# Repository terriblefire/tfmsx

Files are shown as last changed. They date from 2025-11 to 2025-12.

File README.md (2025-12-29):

# TFMSX







A homebrew MSX2 machine using as many of the original chips as possible, with custom CPLD logic to implement the MSX slot system, memory mapper, and bus interface.

## Discord

Join the TF discord for help 

https://discord.gg/Q5zfusgnmH 

## Overview

TFMSX is an open-source hardware implementation of the MSX2 standard that combines authentic MSX chips (VDP, PSG, CPU) with modern programmable logic. The design uses a Xilinx XC95288XL CPLD to handle:

- MSX slot system (4 primary slots + secondary slot expansion)
- Memory mapper (512KB SRAM organized as 32 pages of 16KB)
- I/O address decoding and bus arbitration
- Clock generation and distribution
- Real-time clock (RP5C01A) interface

## Features

- **MSX2 Compatible**: Full MSX2 slot architecture with expansion capability
- **Original Components**: Uses genuine Yamaha V9958 VDP, YM2149 PSG, Z80 CPU
- **512KB RAM**: Memory mapper providing 32 banks of 16KB
- **Real-time Clock**: RP5C01A battery-backed RTC
- **Expansion Slots**: Support for cartridges and expansion boards
- **Multiple Revisions**: Hardware evolved through rev0 → rev1 → rev2 with improvements
- **Comprehensive Testing**: Automated test suite with CI/CD integration

## Hardware Revisions

The current repository contains the **Rev 2** design (see `boards/tfmsxr2/`), which includes:

- Improved audio output and PSG interface
- VDP reset control
- SRAM write enable (SWR pin)
- Fixed WAIT signal generation for proper Z80 timing
- Corrected slot select logic

Previous hardware revisions (Rev 0, Rev 1) are documented in the Eagle design files under `eagle/tfmsx_rev*.brd/sch`.

## Repository Structure

```
tfmsx/
├── rtl/                    # Verilog RTL source code
│   ├── tfmsx_top.v        # Top-level CPLD module
│   ├── clocks.v           # Clock generation (CPU, PSG, slot clocks)
│   └── rp5c01a.v          # Real-time clock module
├── boards/                 # Board-specific build configurations
│   ├── tfmsxr2/           # Revision 2 board (current)
│   ├── Makefile.cpld      # Common CPLD build rules
│   ├── Makefile.inc       # Docker/Xilinx environment setup
│   └── boards.txt         # List of board configurations
├── testsuite/             # Verification test benches
│   ├── bus/               # Bus interface tests (SRAM, ROM, VDP, PSG, slots)
│   │   ├── test_sram_access.v    # SRAM read/write tests
│   │   ├── test_rom_access.v     # ROM access tests
│   │   ├── test_vdp_io.v         # VDP I/O tests
│   │   ├── test_psg_io.v         # PSG I/O tests
│   │   ├── test_slot_access.v    # Slot system tests
│   │   ├── bus_fixture.vinc      # Common test fixture
│   │   ├── bus_tasks.vinc        # Reusable bus cycle tasks
│   │   └── Makefile              # Test build rules
│   ├── rtl/               # Simulation support files (Xilinx primitives)
│   ├── clocks.vinc        # Clock generation for tests
│   ├── unittest.vinc      # Test assertion macros
│   └── Makefile.inc       # Common test environment setup
├── eagle/                 # Eagle CAD hardware designs
│   ├── tfmsx.sch/.brd     # Main board schematic and layout
│   ├── extract_bom.py     # BOM extraction script
│   └── Makefile           # Automated Gerber/PDF/BOM generation
├── roms/                  # MSX system ROM tools
│   ├── Makefile           # Automated ROM download and assembly
│   └── makedefaultroms.sh # Legacy script (deprecated)
└── .github/workflows/        # CI/CD automation
    ├── run-tests.yml         # Automated test execution
    ├── gerbers.yml           # Gerber file generation
    ├── schematic-pdf.yml     # PDF schematic generation
    └── generate_assembly.yml # BOM and CPL generation
```

## Building the CPLD Firmware

### Prerequisites

- **Linux**: Xilinx ISE 10.1 installed at `/opt/Xilinx/10.1/`
- **macOS/Windows**: Docker (automatically builds and uses container)

The build system automatically handles Docker on non-Linux platforms.

### Build All Boards

```bash
cd boards
make all
```

This compiles CPLD firmware for all boards listed in `boards/boards.txt` and generates `.jed` JEDEC programming files.

### Build Specific Board

```bash
cd boards/tfmsxr2
make
```

Output: `tfmsxr2_top.jed` (JEDEC programming file) and `tfmsxr2_top.svf` (Serial Vector Format)

### Clean Build Artifacts

```bash
cd boards
make clean       # Remove intermediate build files
make distclean   # Remove all generated files including .jed
```

### Create Release Package

```bash
cd boards
make zip
```

Generates: `tfmsx_YYYY_MM_DD_<git-hash>.zip` containing all board `.jed` files.

## Programming the CPLD

Flash the CPLD using xc3sprog with an FT232H-based programmer:

```bash
cd boards/tfmsxr2
make flash
```

This requires:
- xc3sprog tool installed
- FT232H USB programmer connected
- Proper JTAG connections to the XC95288XL

## MSX System ROMs

The `roms/` directory contains a Makefile to download and prepare MSX2 system ROMs for use with the TFMSX hardware.

### Building System ROMs

```bash
cd roms
make           # Download ROMs and create default.rom
make -j8       # Parallel download (faster)
make clean     # Remove all generated files
```

The Makefile automatically downloads MSX2 BIOS ROMs from the BlueMSX emulator repository and creates a combined ROM image with multiple banks:

- **Bank 0**: MSX2 (Standard) + MSX2EXT + DISK ROM
- **Bank 1**: MSX2BR (Brazilian) + MSX2BREXT + DISK ROM
- **Bank 2**: MSX2P (MSX2+) + MSX2PEXT + DISK ROM
- **Bank 3**: MSX2SP (Spanish MSX2+) + MSX2SPEXT + DISK ROM

The final output is `default.rom`, which contains all four banks concatenated together. This allows the TFMSX hardware to support multiple MSX2 configurations by bank switching.

**Features**:
- Dependency tracking: Only downloads missing files
- Incremental builds: Only rebuilds changed targets
- Parallel downloads: Use `-j` flag for faster downloads
- Clean target: Easy cleanup with `make clean`

**Note**: These ROMs are copyrighted by their respective manufacturers. Only links are provided. 

## Technical Details

### Memory Map

| Address Range | Function |
|---|---|
| 0x0000-0x3FFF | Page 0 (slot configurable) |
| 0x4000-0x7FFF | Page 1 (slot configurable) |
| 0x8000-0xBFFF | Page 2 (slot configurable) |
| 0xC000-0xFFFF | Page 3 (slot configurable) |

Each page can be mapped to any of 4 slots via the slot register (I/O port 0xA8).

### I/O Port Map

| Port(s) | Device | Function |
|---|---|---|
| 0x98-0x9B | VDP | Yamaha V9958 Video Display Processor |
| 0xA0-0xA3 | PSG | Yamaha YM2149 Programmable Sound Generator |
| 0xA8-0xAB | PPI | 8255 Programmable Peripheral Interface (slot register) |
| 0xB4 | RTC | RP5C01A address latch |
| 0xB5 | RTC | RP5C01A data register |
| 0xFC-0xFF | Mapper | Memory mapper page registers (32 banks × 16KB) |

### Clock Frequencies

- **Master Clock**: 28 MHz (crystal oscillator)
- **CPU Clock (CLKCPU)**: 3.5 MHz (÷8)
- **PSG Clock (PSGCLK)**: 1.75 MHz (÷16)
- **Slot Clock (SLOTCLK)**: 3.5 MHz (÷8)

### CPLD Resources

- **Target Device**: Xilinx XC95288XL-10-TQ144
- **Macrocells**: 288
- **Package**: 144-pin TQFP
- **Speed Grade**: -10 (100 MHz)

Utilization varies by revision but typically uses 70-85% of available macrocells.

## Testing

The `testsuite/` directory contains Verilog testbenches for verifying CPLD functionality. Tests use Icarus Verilog for simulation.

### Running Tests

```bash
cd testsuite/bus
make              # Run all tests
make clean        # Clean generated files
```

### Test Coverage

The test suite includes comprehensive coverage of bus operations:

- **test_sram_access.v**: SRAM read/write operations, chip select timing, mapper control
- **test_rom_access.v**: ROM output enable, address decoding, data bus behavior
- **test_vdp_io.v**: VDP I/O ports (0x98-0x9B), read/write signals, timing
- **test_psg_io.v**: PSG I/O ports (0xA0-0xA2), control signals
- **test_slot_access.v**: MSX slot system, memory mapping, slot registers (0xA8, 0xFC-0xFF)

Each test verifies:
- Correct signal timing and activation
- Proper address decoding
- Bus protocol compliance
- Memory/peripheral access patterns

Tests automatically generate waveform files (`.vcd`) for debugging.

### Continuous Integration

All tests run automatically on push via GitHub Actions. Test status is visible in the badge at the top of this README.

## Development Workflow

1. **Modify RTL**: Edit Verilog files in `rtl/`
2. **Run Tests**: `cd testsuite/bus && make` to verify changes (see [Testing](#testing) section)
3. **Build CPLD**: `cd boards/tfmsxr2 && make`
4. **Flash Hardware**: `make flash` (if hardware available)
5. **Test on Hardware**: Verify functionality on physical board

## VDP Configuration

The TFMSX board supports both V9938 and V9958 video display processors. The VDP chip type is selected using jumpers JP3 and JP4. The CPLD automatically handles all other configuration differences.

### Jumper Settings

| VDP Chip | JP3 (Single Position) | JP4 (Two Position) |
|---|---|---|
| **V9938** | **Closed** | **Left Position** |
| **V9958** | **Open** | **Right Position** |

**Jumper Types**:
- **JP3**: Single position jumper - either closed (jumper installed) or open (no jumper)
- **JP4**: Two position jumper - set to either left or right position

**Configuration Summary**:
- **V9938**: JP3 closed, JP4 left position
- **V9958**: JP3 open, JP4 right position

The CPLD logic uses these jumper settings to configure timing and control signals appropriately for the installed VDP chip.

## Hardware Design Files

Eagle CAD schematics and board layouts are in `eagle/`:

- **Main Board**: `tfmsx.sch` / `tfmsx.brd` (Rev 2 - current design)
- **Previous Revisions**: `tfmsx_rev0.*`, `tfmsx_rev1.*` (historical reference)

### Generating Gerber Files

The `eagle/` directory includes a Makefile for automated Gerber generation using Docker (no Eagle installation required).

```bash
cd eagle
make               # Generate Gerbers for main TFMSX board
make pdf           # Generate PDF schematic for main board
make bom           # Generate Bill of Materials (BOM) CSV
make cpl           # Generate Component Placement List (CPL) CSV
make assembly      # Generate both BOM and CPL for assembly
```

Output files are named with git commit hash and date (e.g., `tfmsx_a1b2c3d_2025_11_14.zip`).

**Requirements**:
- Docker with `terriblefire78/eagle:v1` and `terriblefire78/eagle-pdf` images (for gerbers and PDF)
- Python 3 (for BOM/CPL generation)

### Assembly Files (BOM and CPL)

Generate assembly files for PCB fabrication and assembly:

```bash
cd eagle
make assembly      # Generate both BOM and CPL
```

This creates two files for JLCPCB/PCBA services:

**BOM (`tfmsx_bom.csv`)** contains:
- **Comment**: Component value/part number
- **Designator**: Reference designators (e.g., C1, C2, R5)
- **Footprint**: PCB footprint package
- **LCSC Part #**: LCSC/JLCPCB part number (if available)

**CPL (`tfmsx_cpl.csv`)** contains:
- **Designator**: Component reference
- **Mid X, Mid Y**: Component center position in mm
- **Layer**: Top or Bottom
- **Rotation**: Component rotation in degrees

The BOM groups identical components together for easy ordering and assembly.

## Contributing

This is an open hardware project. Contributions welcome for:

- RTL improvements and optimizations
- Additional test coverage (please include tests for new features)
- Hardware revision suggestions
- Documentation enhancements
- Bug fixes

When contributing RTL changes, please ensure all tests pass by running `cd testsuite/bus && make`.

## License

This work is licensed under the Creative Commons Attribution-NoDerivatives 4.0 International License.

Copyright (c) 2021-2025 Stephen J. Leary

You are free to:
- **Share** - copy and redistribute the material in any medium or format for any purpose, even commercially

Under the following terms:
- **Attribution** - You must give appropriate credit, provide a link to the license, and indicate if changes were made
- **NoDerivatives** - If you remix, transform, or build upon the material, you may not distribute the modified material

See the [LICENSE](LICENSE) file for the complete license text, or visit:
https://creativecommons.org/licenses/by-nd/4.0/

## References

- [MSX Technical Documentation](https://www.msx.org/)
- [MSX Resource Center](https://www.msx.org/wiki/)
- MSX2 Technical Handbook
- Z80 CPU User Manual
- [Yamaha V9958 VDP Documentation](https://www.msx.org/wiki/Yamaha_V9958)

## Contact

For questions, issues, or contributions, please use the GitHub issue tracker.

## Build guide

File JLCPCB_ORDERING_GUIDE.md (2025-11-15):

# JLCPCB Ordering Guide for the **TFMSX** Project

This guide walks you step‑by‑step through ordering the **TFMSX** PCB from JLCPCB using the files provided in the GitHub repository: <https://github.com/terriblefire/tfmsx>

It is written for beginners and assumes **no prior PCB ordering experience**.

---

## 📁 1. Download and Extract the Release Package

1. Go to the GitHub repository: <https://github.com/terriblefire/tfmsx>
2. Open the **Releases** section.
3. Download the **single release ZIP file** (e.g., `tfmsx_v2.0.0.zip`).
4. Extract the ZIP. You will see a structure like this:

```
assembly/
    tfmsx_bom.csv
    tfmsx_cpl.csv

pcb/
    tfmsx_XXXX.zip   (Gerber manufacturing file)

firmware/
    *.jed files

docs/
    PDF documentation
```

The files needed for JLCPCB are:
- **Gerber ZIP file:** located in the `pcb/` folder
- **BOM file:** `assembly/tfmsx_bom.csv`
- **CPL file:** `assembly/tfmsx_cpl.csv`

---

## 🏭 2. Start a PCB Order on JLCPCB

1. Go to **https://jlcpcb.com**
2. Click **"Order Now"** or **"Quote Now"**.
3. Drag and drop the **Gerber ZIP file** into the upload area.

JLCPCB will automatically detect the board size and number of layers.

> **Note:** JLCPCB does *not* always detect PCB thickness. For TFMSX, set **1.6 mm thickness manually**.

---

## ⚙️ 3. Configure the PCB Options (Minimal Setup)

The default settings are fine unless otherwise specified by the project.

Recommended settings:

- **Quantity:** 5 or 10 (your choice)
- **PCB Color:** Any (personal preference)
- **Thickness:** 1.6 mm (set manually if not detected)
- **Surface Finish:** HASL or ENIG (ENIG gives nicer gold pads but costs more)
- **Remove Order Number:** Optional (JLCPCB may charge extra)

Everything else can remain at default unless the project documentation says otherwise.

---

## 🤖 4. Add PCB Assembly (If you want components pre‑soldered)

If this project supports assembly (check the repo):

1. Enable **"PCB Assembly"**
2. Select **Left Side / Top Side** (as required by the project)
3. Upload the following when prompted:
   - **BOM file**
   - **CPL file**

JLCPCB will parse the files and show a component placement preview.

### Review the Assembly Bill of Materials

JLCPCB will display:
- A list of recognised components
- Any unmatched parts (you may need to pick substitutes)
- Costs for assembly

> If any parts show as *"Not Found"*, check the BOM or the GitHub project's documentation for substitute part numbers.

---

## 🔍 5. Review the PCB Preview

You will see:
- The Gerber viewer (copper traces, drill holes, etc.)
- Assembly view (if assembly is enabled)

Make sure:
- The board outline looks correct
- Components appear on the correct side
- No warnings are shown

---

## 🛒 6. Add to Cart and Checkout

1. Click **"Add to Cart"**
2. Verify your order summary
3. Proceed to **Checkout**
4. Enter your shipping address
5. Choose a shipping method (DHL is fastest)
6. Pay using:
   - Credit/Debit card
   - PayPal
   - Other supported methods

---

## 📦 7. Wait for Production

Typical manufacturing times:
- **Bare PCBs:** 2–3 days
- **Assembly:** 3–7 days (depends on part availability)

Shipping time varies by region.

You can track the order progress in your JLCPCB account.

---

## 🎉 8. When the Boards Arrive

Inside the package you will find:
- Your PCBs (bare or assembled)
- Any remaining unused components (for assembly orders)
- QC sticker or summary

Inspect the board visually. If assembled, verify correct component placement.

---

## 🧩 9. Additional Notes for TFMSX Users

- Check the GitHub repo for **firmware**, **build notes**, or **updates**.
- Some components may need to be hand‑soldered depending on the project.
- Refer to the project README for configuration or installation instructions.

---

## ❓ Need Help?
If you want a version with screenshots, clearer beginner steps, or additional troubleshooting (e.g., BOM import errors), just ask and I can extend this document further.

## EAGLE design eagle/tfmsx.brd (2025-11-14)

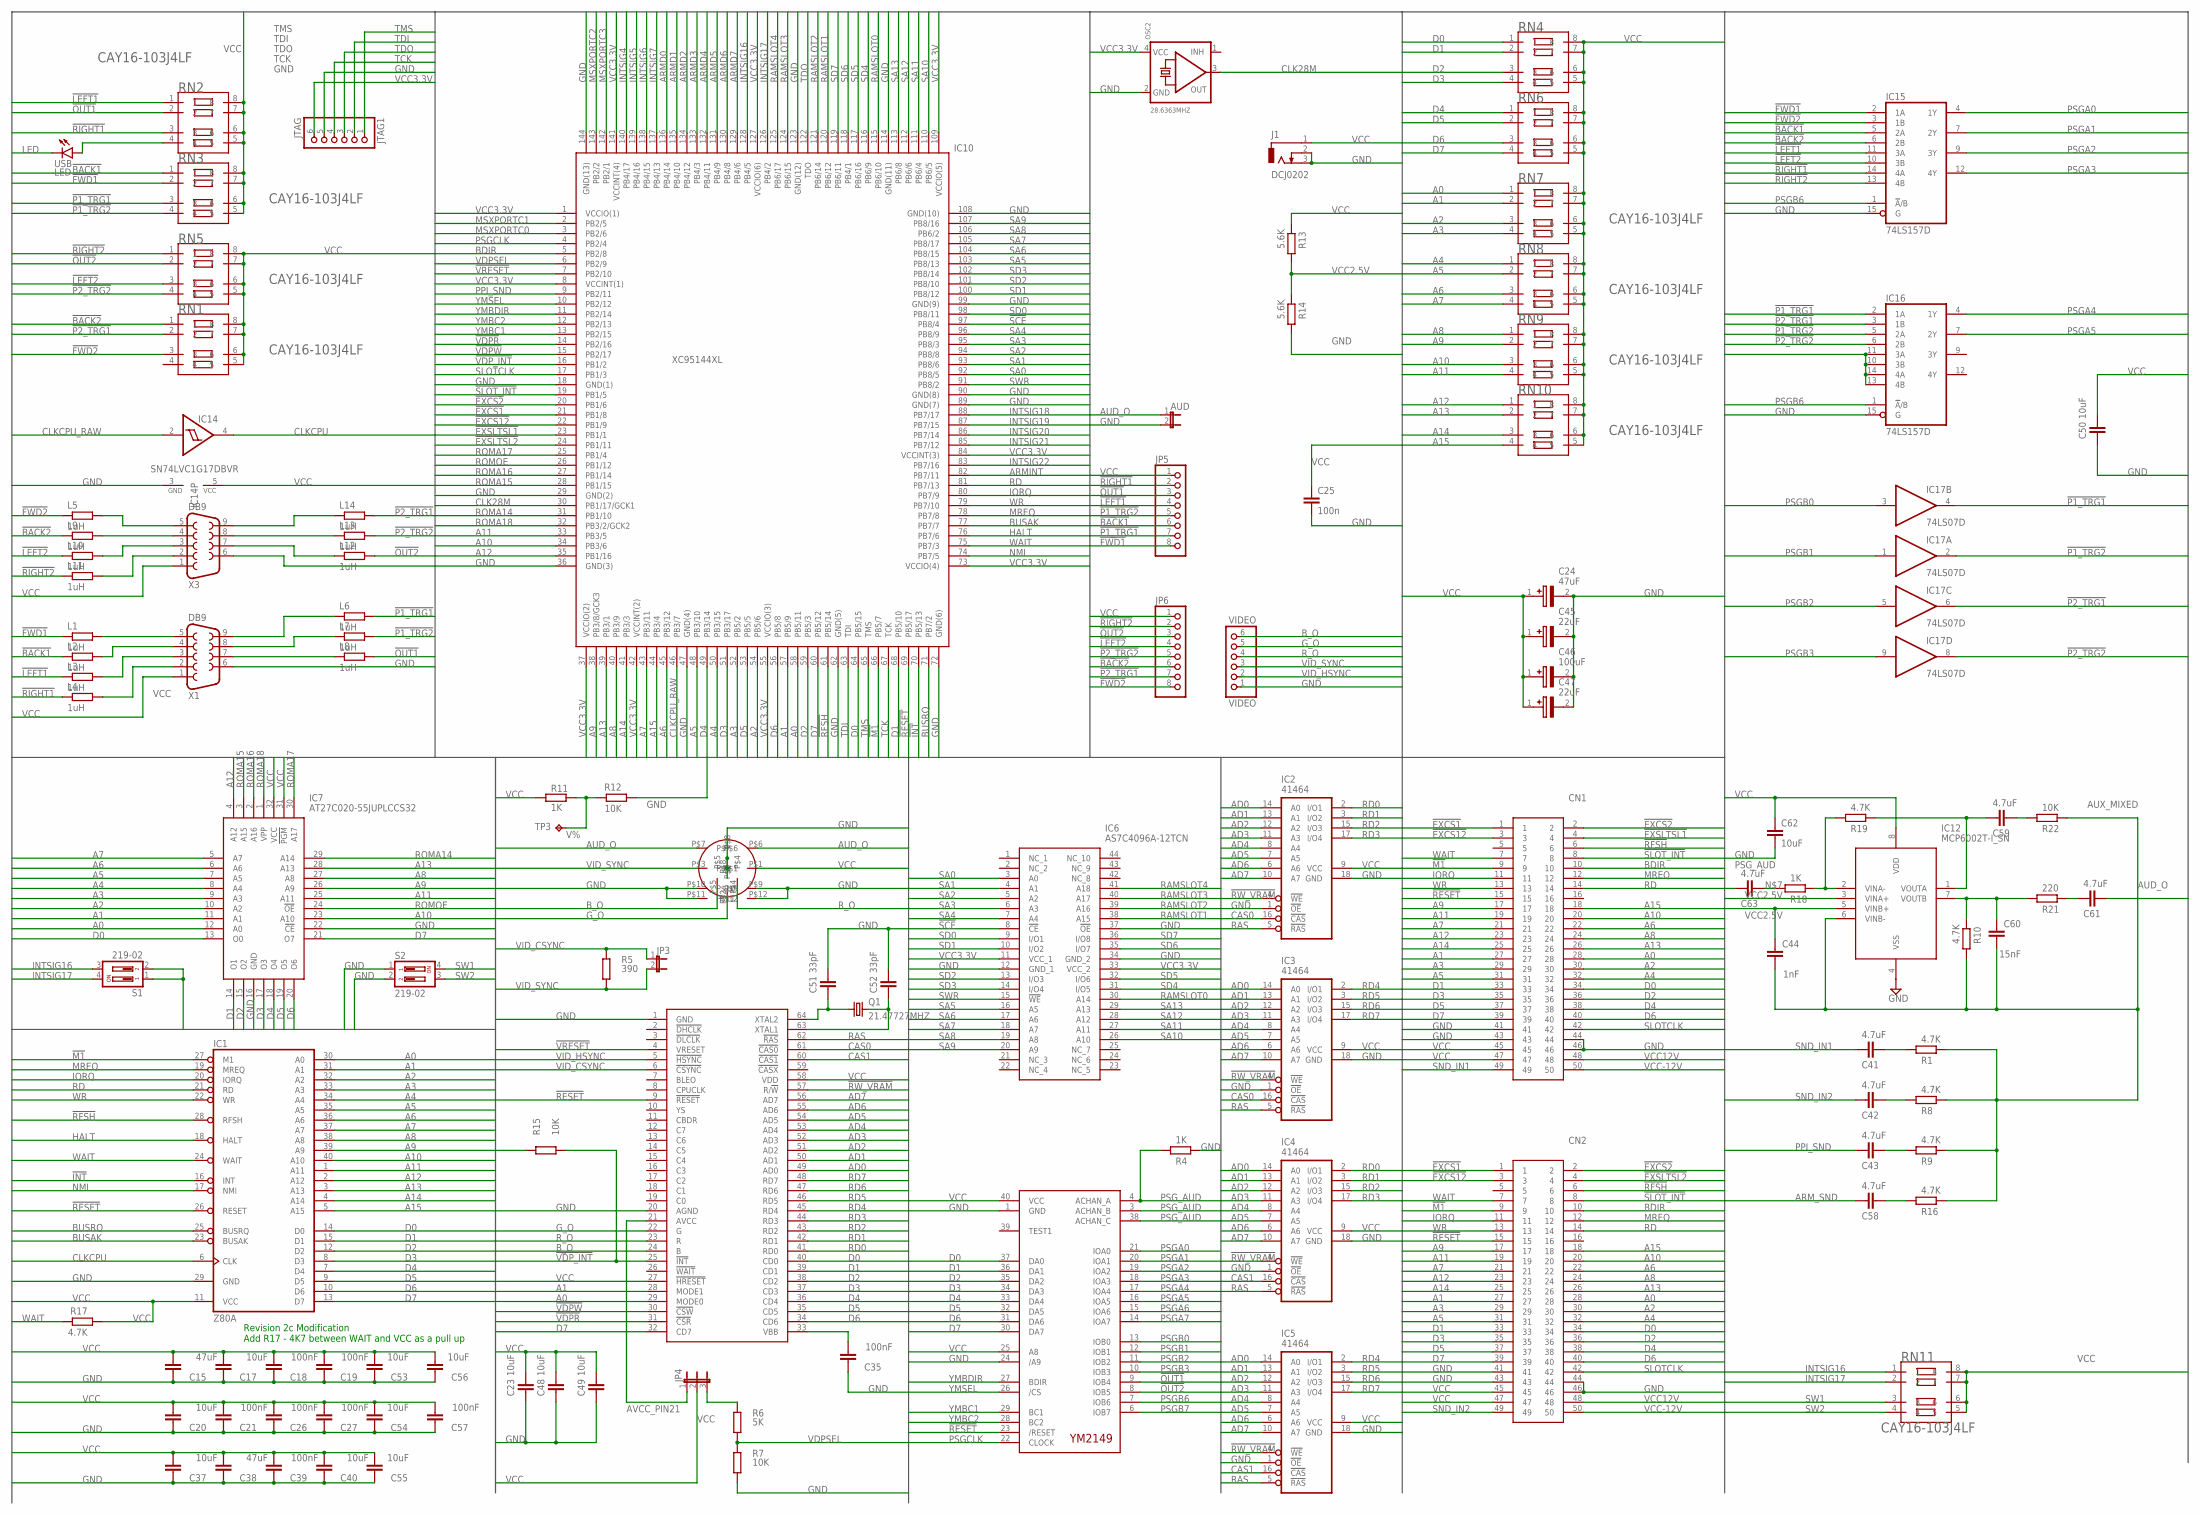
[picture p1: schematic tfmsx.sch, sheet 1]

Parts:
AUD: JUMPER-2PTH; 1X02
C15, C38: 47uF; C1206
C17, C20, C23, C37, C40, C48, C49, C50, C53, C54, C55, C56, C62: 10uF; C1206
C18, C19, C21, C26, C27, C35, C39, C57: 100nF; C1206
C24: 47uF; CAPAE430X550N
C25: 100n; C0603
C41, C42, C43, C58, C59, C61, C63: 4.7uF; C0603
C44: 1nF; C0603
C45, C47: 22uF; CAPAE430X550N
C46: 100uF; CAPAE430X550N
C51, C52: 33pF; C0805
C60: 15nF; C0603
CN1, CN2: 5530843-5; 55308435
IC1: Z80A; DIL40
IC2, IC3, IC4, IC5: 41464; DIL18
IC6: AS7C4096A-12TCN; SOP80P1181X120-44N
IC7: AT27C020-55JUPLCCS32; PLCC-S32
IC9: VDP9958; SOT274
IC10: XC95144XL; SAMACSYS_PARTS_QFP50P2200X2200X160-144N
IC12: MCP6002T-I_SN; SOIC127P600X175-8N
IC13: YM2149; DIL40
IC14: SN74LVC1G17DBVR; SOT23-5
IC15, IC16: 74LS157D; SO16
IC17: 74LS07D; SO14
J1: DCJ0202
JP3: JP1E; JP1
JP4: JP2E; JP2
JP5, JP6: HEADER-1X8ROUND; 1X08_ROUND
JTAG1: JTAG; 1X06_ROUND
L1, L2, L3, L4, L5, L6, L7, L8, L9, L10, L11, L12, L13, L14: 1uH; R1206
OSC2: 28.6363MHZ; OSC_7X5MM
Q1: 21.47727MHZ; HC49/S
R1, R8, R9, R10, R16, R17, R19: 4.7K; M0805
R4, R11, R18: 1K; M0805
R5: 390; M0805
R6: 5K; M0805
R7, R12, R15, R22: 10K; M0805
R13, R14: 5.6K; M0805
R21: 220; M0805
RN1, RN2, RN3, RN4, RN5, RN6, RN7, RN8, RN9, RN10, RN11: CAY16-103J4LF; RESCAXE80P320X160-8N
S1, S2: 219-02; CTS-219-02
TP3: TPB1,27; B1,27
U$3: DIN45326; 838_DIN8
USB: LED; SML0805
VIDEO: VIDEO; 1X06_ROUND
X1, X3: DB9; F09HP

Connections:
!BACK1: IC15.5 (2A), JP5.6, L2.1, RN3.1; also elsewhere on the board
!BACK1_B: L2.2, X1.4
!BACK2: IC15.6 (2B), JP6.6, L9.1, RN1.1
!EXCS1: CN1.1, CN2.1, IC10.21 (PB1/8)
!EXCS2: CN1.2, CN2.2, IC10.20 (PB1/6)
!EXCS12: CN1.3, CN2.3, IC10.22 (PB1/9)
!EXSLTSL1: CN1.4, IC10.23 (PB1/1)
!EXSLTSL2: CN2.4, IC10.24 (PB1/11)
!FWD1: IC15.2 (1A), JP5.8, L1.1, RN3.2; also elsewhere on the board
!FWD1_B: L1.2, X1.5
!FWD2: IC15.3 (1B), JP6.8, L5.1, RN1.3
!INT: IC1.16 (INT), IC10.70 (PB5/13)
!LEFT1: IC15.11 (3A), JP5.4, L3.1, RN2.1; also elsewhere on the board
!LEFT1_B: L3.2, X1.3
!LEFT2: IC15.10 (3B), JP6.4, L10.1, RN5.3
!M1: CN1.9, CN2.9, IC1.27 (M1), IC10.66 (PB5/7)
!OUT1: IC13.9 (IOB4), JP5.3, L8.2, RN2.2; also elsewhere on the board
!OUT2: IC13.8 (IOB5), JP6.3, L12.2, RN5.2
!P1_TRG1: IC16.2 (1A), IC17.4 (O), JP5.7, L6.2, RN3.3; also elsewhere on the board
!P1_TRG2: IC16.5 (2A), IC17.2 (O), JP5.5, L7.2, RN3.4; also elsewhere on the board
!P2_TRG1: IC16.3 (1B), IC17.6 (O), JP6.7, L14.2, RN1.2
!P2_TRG2: IC16.6 (2B), IC17.8 (O), JP6.5, L13.2, RN5.4
!RESET: CN1.15, CN2.15, IC1.26 (RESET), IC9.9 (!RESET), IC10.69 (PB5/17), IC13.23 (/RESET)
!RFSH: CN1.6, CN2.6, IC1.28 (RFSH), IC10.61 (PB5/14)
!RIGHT1: IC15.14 (4A), JP5.2, L4.1, RN2.3; also elsewhere on the board
!RIGHT1_B: L4.2, X1.2
!RIGHT2: IC15.13 (4B), JP6.2, L11.1, RN5.1
!RW_VRAM: IC2.4 (!WE), IC3.4 (!WE), IC4.4 (!WE), IC5.4 (!WE), IC9.57 (R/!W)
!SCE: IC6.8 (!CE), IC10.97 (PB8/4)
!SLOT_INT: CN1.8, CN2.8, IC10.19 (PB1/5)
!VDPR: IC9.31 (!CSR), IC10.14 (PB2/16)
!VDPW: IC9.30 (!CSW), IC10.15 (PB2/17)
!VDP_INT: IC9.25 (!INT), IC10.16 (PB1/2), R15.1
!VRESET: IC9.4 (VRESET), IC10.7 (PB2/10)
A0: CN1.28, CN2.28, IC1.30 (A0), IC7.12 (A0), IC9.29 (MODE0), IC10.58 (PB5/11), RN7.1
A1: CN1.27, CN2.27, IC1.31 (A1), IC7.11 (A1), IC9.28 (MODE1), IC10.57 (PB5/9), RN7.2
A2: CN1.30, CN2.30, IC1.32 (A2), IC7.10 (A2), IC10.54 (PB5/6), RN7.3
A3: CN1.29, CN2.29, IC1.33 (A3), IC7.9 (A3), IC10.52 (PB5/2), RN7.4
A4: CN1.32, CN2.32, IC1.34 (A4), IC7.8 (A4), IC10.50 (PB3/15), RN8.1
A5: CN1.31, CN2.31, IC1.35 (A5), IC7.7 (A5), IC10.48 (PB3/10), RN8.2
A6: CN1.22, CN2.22, IC1.36 (A6), IC7.6 (A6), IC10.45 (PB3/12), RN8.3
A7: CN1.21, CN2.21, IC1.37 (A7), IC7.5 (A7), IC10.43 (PB3/11), RN8.4
A8: CN1.24, CN2.24, IC1.38 (A8), IC7.27 (A8), IC10.40 (PB3/9), RN9.1
A9: CN1.17, CN2.17, IC1.39 (A9), IC7.26 (A9), IC10.38 (PB3/8/GCK3), RN9.2
A10: CN1.20, CN2.20, IC1.40 (A10), IC7.23 (A10), IC10.34 (PB3/6), RN9.3
A11: CN1.19, CN2.19, IC1.1 (A11), IC7.25 (A11), IC10.33 (PB3/5), RN9.4
A12: CN1.23, CN2.23, IC1.2 (A12), IC7.4 (A12), IC10.35 (PB1/16), RN10.1
A13: CN1.26, CN2.26, IC1.3 (A13), IC7.28 (A13), IC10.39 (PB3/1), RN10.2
A14: CN1.25, CN2.25, IC1.4 (A14), IC10.41 (PB3/3), RN10.3
A15: CN1.18, CN2.18, IC1.5 (A15), IC10.44 (PB3/4), RN10.4
AD0: IC2.14 (A0), IC3.14 (A0), IC4.14 (A0), IC5.14 (A0), IC9.49 (AD0)
AD1: IC2.13 (A1), IC3.13 (A1), IC4.13 (A1), IC5.13 (A1), IC9.50 (AD1)
AD2: IC2.12 (A2), IC3.12 (A2), IC4.12 (A2), IC5.12 (A2), IC9.51 (AD2)
AD3: IC2.11 (A3), IC3.11 (A3), IC4.11 (A3), IC5.11 (A3), IC9.52 (AD3)
AD4: IC2.8 (A4), IC3.8 (A4), IC4.8 (A4), IC5.8 (A4), IC9.53 (AD4)
AD5: IC2.7 (A5), IC3.7 (A5), IC4.7 (A5), IC5.7 (A5), IC9.54 (AD5)
AD6: IC2.6 (A6), IC3.6 (A6), IC4.6 (A6), IC5.6 (A6), IC9.55 (AD6)
AD7: IC2.10 (A7), IC3.10 (A7), IC4.10 (A7), IC5.10 (A7), IC9.56 (AD7)
ARMD0: IC10.136 (PB4/14); also elsewhere on the board
ARMD1: IC10.135 (PB4/10); also elsewhere on the board
ARMD2: IC10.134 (PB4/12); also elsewhere on the board
ARMD3: IC10.133 (PB4/3); also elsewhere on the board
ARMD4: IC10.132 (PB4/11); also elsewhere on the board
ARMD5: IC10.131 (PB4/9); also elsewhere on the board
ARMD6: IC10.130 (PB4/8); also elsewhere on the board
ARMD7: IC10.129 (PB4/6); also elsewhere on the board
ARMINT: IC10.82 (PB7/11); also elsewhere on the board
ARM_SND: C58.1; also elsewhere on the board
AUD_O: AUD.1, C61.2, U$3.P$6, U$3.P$7
AUX_MIXED: C44.1, C60.1, IC12.6 (VINB-), R1.1, R8.1, R9.1, R10.2, R16.1, R22.1
AVCC_PIN21: IC9.21 (AVCC), JP4.1
BDIR: CN1.10, CN2.10, IC10.5 (PB2/8)
BUSAK: IC1.23 (BUSAK), IC10.77 (PB7/7)
BUSRQ: IC1.25 (BUSRQ), IC10.71 (PB7/2)
B_O: IC9.24 (B), U$3.P$5, VIDEO.6
CAS0: IC2.16 (!CAS), IC3.16 (!CAS), IC9.61 (!CAS0)
CAS1: IC4.16 (!CAS), IC5.16 (!CAS), IC9.60 (!CAS1)
CLK28M: IC10.30 (PB1/17/GCK1), OSC2.3 (OUT)
CLKCPU: IC1.6 (CLK), IC14.4 (O)
CLKCPU_RAW: IC10.46 (PB3/7), IC14.2 (I)
D0: CN1.34, CN2.34, IC1.14 (D0), IC7.13 (O0), IC9.40 (CD0), IC10.64 (PB5/15), IC13.37 (DA0), RN4.1
D1: CN1.33, CN2.33, IC1.15 (D1), IC7.14 (O1), IC9.39 (CD1), IC10.68 (PB5/10), IC13.36 (DA1), RN4.2
D2: CN1.36, CN2.36, IC1.12 (D2), IC7.15 (O2), IC9.38 (CD2), IC10.59 (PB5/3), IC13.35 (DA2), RN4.3
D3: CN1.35, CN2.35, IC1.8 (D3), IC7.17 (O3), IC9.37 (CD3), IC10.51 (PB3/17), IC13.34 (DA3), RN4.4
D4: CN1.38, CN2.38, IC1.7 (D4), IC7.18 (O4), IC9.36 (CD4), IC10.49 (PB3/14), IC13.33 (DA4), RN6.1
D5: CN1.37, CN2.37, IC1.9 (D5), IC7.19 (O5), IC9.35 (CD5), IC10.53 (PB5/5), IC13.32 (DA5), RN6.2
D6: CN1.40, CN2.40, IC1.10 (D6), IC7.20 (O6), IC9.34 (CD6), IC10.56 (PB5/8), IC13.31 (DA6), RN6.3
D7: CN1.39, CN2.39, IC1.13 (D7), IC7.21 (O7), IC9.32 (CD7), IC10.60 (PB5/12), IC13.30 (DA7), RN6.4
GND: AUD.2, C15.1, C17.1, C18.1, C19.1, C20.1, C21.1, C23.1, C24.2 (-), C25.2, C26.1, C27.1, C35.1, C37.1, C38.1, C39.1, C40.1, C45.2 (-), C46.2 (-), C47.2 (-), C48.1, C49.1, C50.1, C51.2, C52.2, C53.1, C54.1, C55.1, C56.1, C57.1, C62.2, CN1.41, CN1.43, CN1.44, CN1.46, CN2.41, CN2.43, CN2.44, CN2.46, IC1.29 (GND), IC2.1 (!OE), IC2.18 (GND), IC3.1 (!OE), IC3.18 (GND), IC4.1 (!OE), IC4.18 (GND), IC5.1 (!OE), IC5.18 (GND), IC6.12 (GND_1), IC6.34 (GND_2), IC6.37 (!OE), IC7.16 (GND), IC7.22 (!CE), IC9.1 (GND), IC9.20 (AGND), IC10.18 (GND(1)), IC10.29 (GND(2)), IC10.36 (GND(3)), IC10.47 (GND(4)), IC10.62 (GND(5)), IC10.72 (GND(6)), IC10.89 (GND(7)), IC10.90 (GND(8)), IC10.99 (GND(9)), IC10.108 (GND(10)), IC10.114 (GND(11)), IC10.123 (GND(12)), IC10.144 (GND(13)), IC12.4 (VSS), IC13.1 (GND), IC13.24 (/A9), IC14.3 (GND), IC15.8 (GND), IC15.15 (G), IC16.8 (GND), IC16.10 (3B), IC16.11 (3A), IC16.13 (4B), IC16.14 (4A), IC16.15 (G), IC17.7 (GND), J1.2, J1.3, JTAG1.5, OSC2.2 (GND), R4.1, R7.1, R12.1, R14.2, S1.1, S1.2, S2.1, S2.2, U$3.P$8, U$3.P$9, U$3.P$10, U$3.P$11, U$3.P$12, VIDEO.1, X1.6, X3.6; also elsewhere on the board
G_O: IC9.22 (G), U$3.P$2, VIDEO.5
HALT: IC1.18 (HALT), IC10.76 (PB7/6)
INTSIG4: IC10.140 (PB4/17); also elsewhere on the board
INTSIG5: IC10.139 (PB4/16); also elsewhere on the board
INTSIG6: IC10.138 (PB4/15); also elsewhere on the board
INTSIG7: IC10.137 (PB4/13); also elsewhere on the board
INTSIG16: IC10.128 (PB4/5), RN11.1, S1.3; also elsewhere on the board
INTSIG17: IC10.126 (PB4/2), RN11.2, S1.4; also elsewhere on the board
INTSIG18: IC10.88 (PB7/17); also elsewhere on the board
INTSIG19: IC10.87 (PB7/15); also elsewhere on the board
INTSIG20: IC10.86 (PB7/14); also elsewhere on the board
INTSIG21: IC10.85 (PB7/12); also elsewhere on the board
INTSIG22: IC10.83 (PB7/16); also elsewhere on the board
IORQ: CN1.11, CN2.11, IC1.20 (IORQ), IC10.80 (PB7/9)
LED: USB.C; also elsewhere on the board
MREQ: CN1.12, CN2.12, IC1.19 (MREQ), IC10.78 (PB7/8)
MSXPORTC0: IC10.3 (PB2/6); also elsewhere on the board
MSXPORTC1: IC10.2 (PB2/5); also elsewhere on the board
MSXPORTC2: IC10.143 (PB2/2); also elsewhere on the board
MSXPORTC3: IC10.142 (PB2/1); also elsewhere on the board
unnamed: C51.1, IC9.64 (XTAL2), Q1.1
unnamed: C52.1, IC9.63 (XTAL1), Q1.2
unnamed: C35.2, IC9.33 (VBB)
unnamed: L8.1, X1.7
unnamed: L7.1, X1.8
unnamed: L6.1, X1.9
unnamed: C63.2, R18.2
unnamed: L9.2, X3.4
unnamed: L10.2, X3.3
unnamed: L11.2, X3.2
unnamed: L5.2, X3.5
unnamed: L12.1, X3.7
unnamed: L13.1, X3.8
unnamed: L14.1, X3.9
unnamed: RN2.4, USB.A
unnamed: C41.2, R1.2
unnamed: C42.2, R8.2
unnamed: C43.2, R9.2
unnamed: C58.2, R16.2
unnamed: JP4.3, R6.2
unnamed: IC12.2 (VINA-), R18.1, R19.2
unnamed: C59.1, IC12.1 (VOUTA), R19.1
unnamed: C59.2, R22.2
unnamed: C60.2, IC12.7 (VOUTB), R10.1, R21.2
unnamed: C61.1, R21.1
NMI: IC1.17 (NMI), IC10.74 (PB7/5)
PPI_SND: C43.1, IC10.9 (PB2/11)
PSGA0: IC13.21 (IOA0), IC15.4 (1Y)
PSGA1: IC13.20 (IOA1), IC15.7 (2Y)
PSGA2: IC13.19 (IOA2), IC15.9 (3Y)
PSGA3: IC13.18 (IOA3), IC15.12 (4Y)
PSGA4: IC13.17 (IOA4), IC16.4 (1Y)
PSGA5: IC13.16 (IOA5), IC16.7 (2Y)
PSGA6: IC13.15 (IOA6)
PSGA7: IC13.14 (IOA7)
PSGB0: IC13.13 (IOB0), IC17.3 (I)
PSGB1: IC13.12 (IOB1), IC17.1 (I)
PSGB2: IC13.11 (IOB2), IC17.5 (I)
PSGB3: IC13.10 (IOB3), IC17.9 (I)
PSGB6: IC13.7 (IOB6), IC15.1 (!A!/B), IC16.1 (!A!/B)
PSGB7: IC13.6 (IOB7)
PSGCLK: IC10.4 (PB2/4), IC13.22 (CLOCK)
PSG_AUD: C63.1, IC13.3 (ACHAN_B), IC13.4 (ACHAN_A), IC13.38 (ACHAN_C), R4.2
RAMSLOT0: IC6.30 (A14), IC10.115 (PB6/10)
RAMSLOT1: IC6.38 (A15), IC10.120 (PB6/12)
RAMSLOT2: IC6.39 (A16), IC10.121 (PB6/14)
RAMSLOT3: IC6.40 (A17), IC10.124 (PB6/15)
RAMSLOT4: IC6.41 (A18), IC10.125 (PB6/17)
RAS: IC2.5 (!RAS), IC3.5 (!RAS), IC4.5 (!RAS), IC5.5 (!RAS), IC9.62 (!RAS)
RD: CN1.14, CN2.14, IC1.21 (RD), IC10.81 (PB7/13)
RD0: IC2.2 (I/O1), IC4.2 (I/O1), IC9.41 (RD0)
RD1: IC2.3 (I/O2), IC4.3 (I/O2), IC9.42 (RD1)
RD2: IC2.15 (I/O3), IC4.15 (I/O3), IC9.43 (RD2)
RD3: IC2.17 (I/O4), IC4.17 (I/O4), IC9.44 (RD3)
RD4: IC3.2 (I/O1), IC5.2 (I/O1), IC9.45 (RD4)
RD5: IC3.3 (I/O2), IC5.3 (I/O2), IC9.46 (RD5)
RD6: IC3.15 (I/O3), IC5.15 (I/O3), IC9.47 (RD6)
RD7: IC3.17 (I/O4), IC5.17 (I/O4), IC9.48 (RD7)
ROMA14: IC7.29 (A14), IC10.31 (PB1/10)
ROMA15: IC7.3 (A15), IC10.28 (PB1/15)
ROMA16: IC7.2 (A16), IC10.27 (PB1/14)
ROMA17: IC7.30 (A17), IC10.25 (PB1/4)
ROMA18: IC7.1 (VPP), IC10.32 (PB3/2/GCK2)
ROMOE: IC7.24 (!OE), IC10.26 (PB1/12)
R_O: IC9.23 (R), U$3.P$4, VIDEO.4
SA0: IC6.3 (A0), IC10.92 (PB8/5)
SA1: IC6.4 (A1), IC10.93 (PB8/6)
SA2: IC6.5 (A2), IC10.94 (PB8/8)
SA3: IC6.6 (A3), IC10.95 (PB8/3)
SA4: IC6.7 (A4), IC10.96 (PB8/9)
SA5: IC6.16 (A5), IC10.103 (PB8/13)
SA6: IC6.17 (A6), IC10.104 (PB8/15)
SA7: IC6.18 (A7), IC10.105 (PB8/17)
SA8: IC6.19 (A8), IC10.106 (PB6/2)
SA9: IC6.20 (A9), IC10.107 (PB8/16)
SA10: IC6.26 (A10), IC10.110 (PB6/5)
SA11: IC6.27 (A11), IC10.111 (PB6/4)
SA12: IC6.28 (A12), IC10.112 (PB6/6)
SA13: IC6.29 (A13), IC10.113 (PB6/8)
SD0: IC6.9 (I/O1), IC10.98 (PB8/11)
SD1: IC6.10 (I/O2), IC10.100 (PB8/12)
SD2: IC6.13 (I/O3), IC10.101 (PB8/10)
SD3: IC6.14 (I/O4), IC10.102 (PB8/14)
SD4: IC6.31 (I/O5), IC10.116 (PB6/9)
SD5: IC6.32 (I/O6), IC10.117 (PB6/16)
SD6: IC6.35 (I/O7), IC10.118 (PB4/1)
SD7: IC6.36 (I/O8), IC10.119 (PB6/11)
SLOTCLK: CN1.42, CN2.42, IC10.17 (PB1/3)
SND_IN1: C41.1, CN1.49
SND_IN2: C42.1, CN2.49
SW1: RN11.3, S2.4; also elsewhere on the board
SW2: RN11.4, S2.3; also elsewhere on the board
SWR: IC6.15 (!WE), IC10.91 (PB8/2)
TCK: IC10.67 (TCK), JTAG1.4
TDI: IC10.63 (TDI), JTAG1.2
TDO: IC10.122 (TDO), JTAG1.3
TMS: IC10.65 (TMS), JTAG1.1
V%: R11.1, R12.2, TP3.TP
VCC: C15.2, C17.2, C18.2, C19.2, C20.2, C21.2, C23.2, C24.1 (+), C25.1, C26.2, C27.2, C37.2, C38.2, C39.2, C40.2, C45.1 (+), C46.1 (+), C47.1 (+), C48.2, C49.2, C50.2, C53.2, C54.2, C55.2, C56.2, C57.2, C62.1, CN1.45, CN1.47, CN2.45, CN2.47, IC1.11 (VCC), IC2.9 (VCC), IC3.9 (VCC), IC4.9 (VCC), IC5.9 (VCC), IC7.31 (!PGM), IC7.32 (VCC), IC9.27 (!HRESET), IC9.58 (VDD), IC12.8 (VDD), IC13.25 (A8), IC13.40 (VCC), IC14.5 (VCC), IC15.16 (VCC), IC16.16 (VCC), IC17.14 (VCC), J1.1, JP4.2, JP5.1, JP6.1, R11.2, R13.1, R15.2, R17.2, RN1.5, RN1.6, RN1.7, RN1.8, RN2.5, RN2.6, RN2.7, RN2.8, RN3.5, RN3.6, RN3.7, RN3.8, RN4.5, RN4.6, RN4.7, RN4.8, RN5.5, RN5.6, RN5.7, RN5.8, RN6.5, RN6.6, RN6.7, RN6.8, RN7.5, RN7.6, RN7.7, RN7.8, RN8.5, RN8.6, RN8.7, RN8.8, RN9.5, RN9.6, RN9.7, RN9.8, RN10.5, RN10.6, RN10.7, RN10.8, RN11.5, RN11.6, RN11.7, RN11.8, U$3.P$1, X1.1, X3.1; also elsewhere on the board
VCC2.5V: C44.2, IC12.3 (VINA+), IC12.5 (VINB+), R13.2, R14.1
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

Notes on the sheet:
Revision 2c Modification Add R17 - 4K7 between WAIT and VCC as a pull up

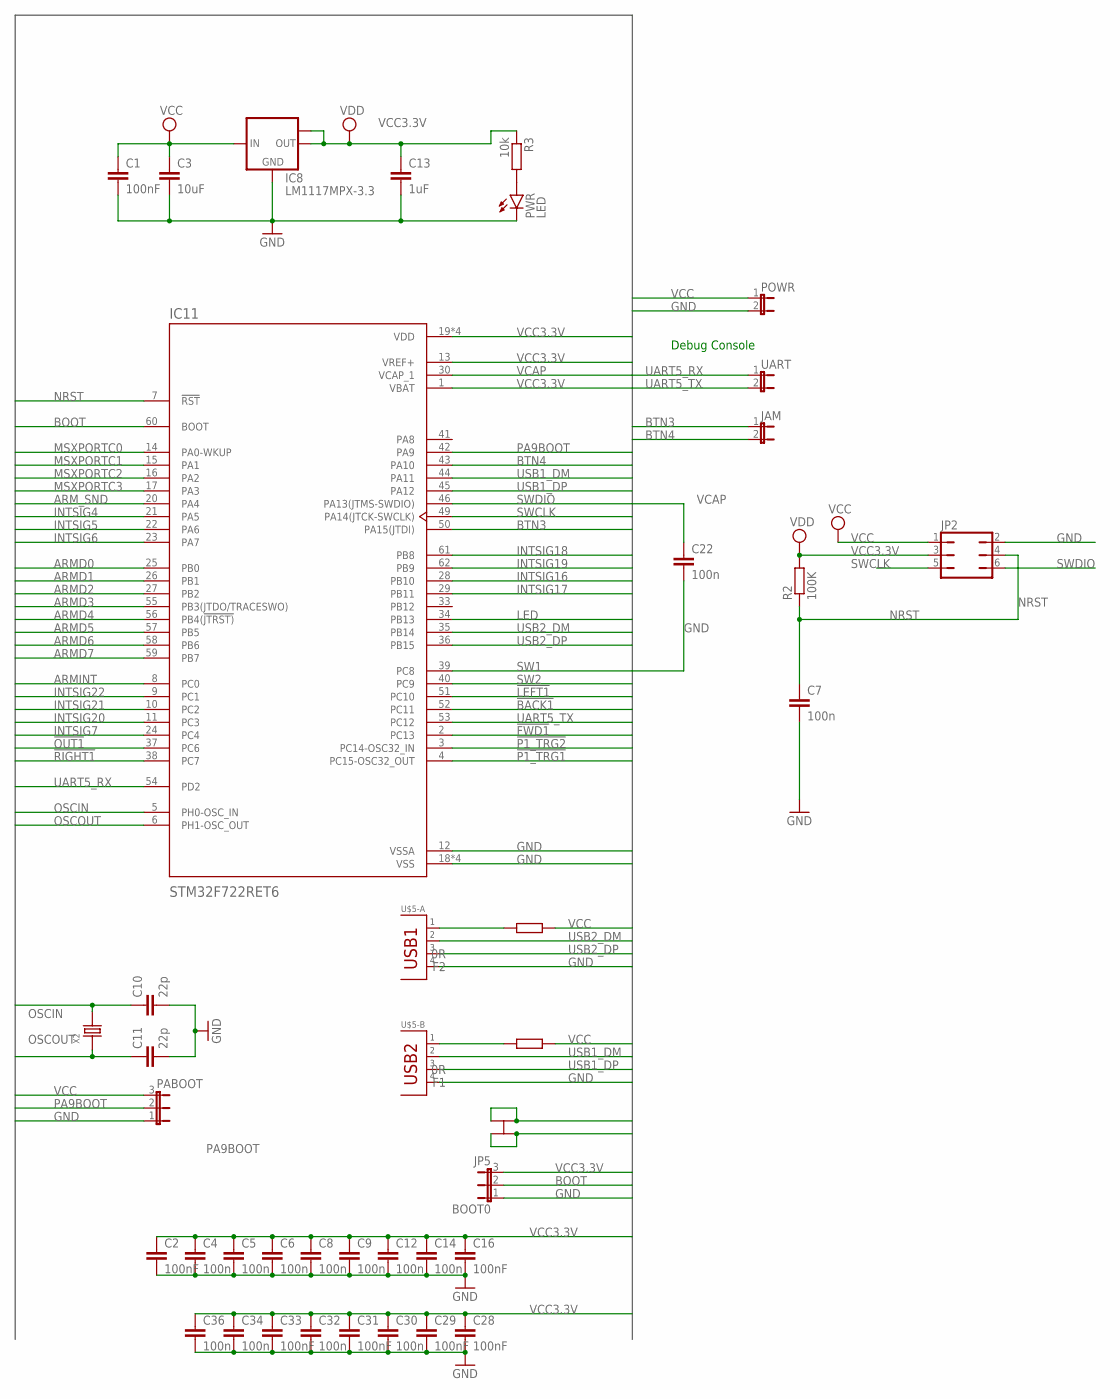
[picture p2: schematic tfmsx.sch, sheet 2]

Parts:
BOOT0: JP5; JP2
C1: 100nF; C1206
C2, C16, C28, C29, C31, C33: 100nF; C0603
C3: 10uF; C0603
C4, C5, C6, C7, C8, C9, C12, C14, C30, C32, C34, C36: 100n; C0603
C10, C11: 22p; C0603
C13: 1uF; C1206
C22: 100n; C0805
F1, F2: 0R; R1206
IC8: LM1117MPX-3.3; SOT223
IC11: STM32F722RET6; QFP50P1200X1200X160-64N
JAM: JUMPER-2PTH; 1X02
JP2: JP3Q
PA9BOOT: PABOOT; JP2
POWR: JUMPER-2PTH; 1X02
PWR: LED; SML0805
R2: 100K; M0805
R3: 10k; R0603
U$5: USB-A-2_USB_USB-A-2
UART: JUMPER-2PTH; 1X02
X2: SMD-CRYSTAL-25MHZ-20PF-20PPM(2P-5.0X3.2MM); X2-SMD-5.0X3.2X1.3MM

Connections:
!BACK1: IC11.52 (PC11); also elsewhere on the board
!FWD1: IC11.2 (PC13); also elsewhere on the board
!LEFT1: IC11.51 (PC10); also elsewhere on the board
!OUT1: IC11.37 (PC6); also elsewhere on the board
!P1_TRG1: IC11.4 (PC15-OSC32_OUT); also elsewhere on the board
!P1_TRG2: IC11.3 (PC14-OSC32_IN); also elsewhere on the board
!RIGHT1: IC11.38 (PC7); also elsewhere on the board
ARMD0: IC11.25 (PB0); also elsewhere on the board
ARMD1: IC11.26 (PB1); also elsewhere on the board
ARMD2: IC11.27 (PB2); also elsewhere on the board
ARMD3: IC11.55 (PB3(JTDO/TRACESWO)); also elsewhere on the board
ARMD4: IC11.56 (PB4(!JTRST)); also elsewhere on the board
ARMD5: IC11.57 (PB5); also elsewhere on the board
ARMD6: IC11.58 (PB6); also elsewhere on the board
ARMD7: IC11.59 (PB7); also elsewhere on the board
ARMINT: IC11.8 (PC0); also elsewhere on the board
ARM_SND: IC11.20 (PA4); also elsewhere on the board
BOOT: BOOT0.2, IC11.60 (BOOT)
BTN3: IC11.50 (PA15(JTDI)), JAM.1
BTN4: IC11.43 (PA10), JAM.2
GND: BOOT0.1, C1.2, C2.2, C3.2, C4.2, C5.2, C6.2, C7.2, C8.2, C9.2, C10.2, C11.2, C12.2, C13.2, C14.2, C16.2, C22.2, C28.2, C29.2, C30.2, C31.2, C32.2, C33.2, C34.2, C36.2, IC8.1 (GND), IC11.12 (VSSA), IC11.18 (VSS), IC11.31 (VSS), IC11.47 (VSS), IC11.63 (VSS), JP2.2, PA9BOOT.1, POWR.2, PWR.C, U$5.1-4, U$5.2-4, U$5.SHIELD1, U$5.SHIELD2, U$5.SHIELD3, U$5.SHIELD4; also elsewhere on the board
INTSIG4: IC11.21 (PA5); also elsewhere on the board
INTSIG5: IC11.22 (PA6); also elsewhere on the board
INTSIG6: IC11.23 (PA7); also elsewhere on the board
INTSIG7: IC11.24 (PC4); also elsewhere on the board
INTSIG16: IC11.28 (PB10); also elsewhere on the board
INTSIG17: IC11.29 (PB11); also elsewhere on the board
INTSIG18: IC11.61 (PB8); also elsewhere on the board
INTSIG19: IC11.62 (PB9); also elsewhere on the board
INTSIG20: IC11.11 (PC3); also elsewhere on the board
INTSIG21: IC11.10 (PC2); also elsewhere on the board
INTSIG22: IC11.9 (PC1); also elsewhere on the board
LED: IC11.34 (PB13); also elsewhere on the board
MSXPORTC0: IC11.14 (PA0-WKUP); also elsewhere on the board
MSXPORTC1: IC11.15 (PA1); also elsewhere on the board
MSXPORTC2: IC11.16 (PA2); also elsewhere on the board
MSXPORTC3: IC11.17 (PA3); also elsewhere on the board
unnamed: PWR.A, R3.2
unnamed: F1.2, U$5.2-1
unnamed: F2.2, U$5.1-1
NRST: C7.1, IC11.7 (!RST), JP2.4, R2.1
OSCIN: C10.1, IC11.5 (PH0-OSC_IN), X2.2
OSCOUT: C11.1, IC11.6 (PH1-OSC_OUT), X2.1
PA9BOOT: IC11.42 (PA9), PA9BOOT.2
SW1: IC11.39 (PC8); also elsewhere on the board
SW2: IC11.40 (PC9); also elsewhere on the board
SWCLK: IC11.49 (PA14(JTCK-SWCLK)), JP2.5
SWDIO: IC11.46 (PA13(JTMS-SWDIO)), JP2.6
UART5_RX: IC11.54 (PD2), UART.1
UART5_TX: IC11.53 (PC12), UART.2
USB1_DM: IC11.44 (PA11), U$5.2-2
USB1_DP: IC11.45 (PA12), U$5.2-3
USB2_DM: IC11.35 (PB14), U$5.1-2
USB2_DP: IC11.36 (PB15), U$5.1-3
VCAP: C22.1, IC11.30 (VCAP_1)
VCC: C1.1, C3.1, F1.1, F2.1, IC8.3 (IN), JP2.1, PA9BOOT.3, POWR.1; also elsewhere on the board
VCC3.3V: BOOT0.3, C2.1, C4.1, C5.1, C6.1, C8.1, C9.1, C12.1, C13.1, C14.1, C16.1, C28.1, C29.1, C30.1, C31.1, C32.1, C33.1, C34.1, C36.1, IC8.2 (OUT), IC8.TAB (OUT1), IC11.1 (VBAT), IC11.13 (VREF+), IC11.19 (VDD), IC11.32 (VDD), IC11.48 (VDD), IC11.64 (VDD), JP2.3, R2.2, R3.1; also elsewhere on the board

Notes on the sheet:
Debug Console

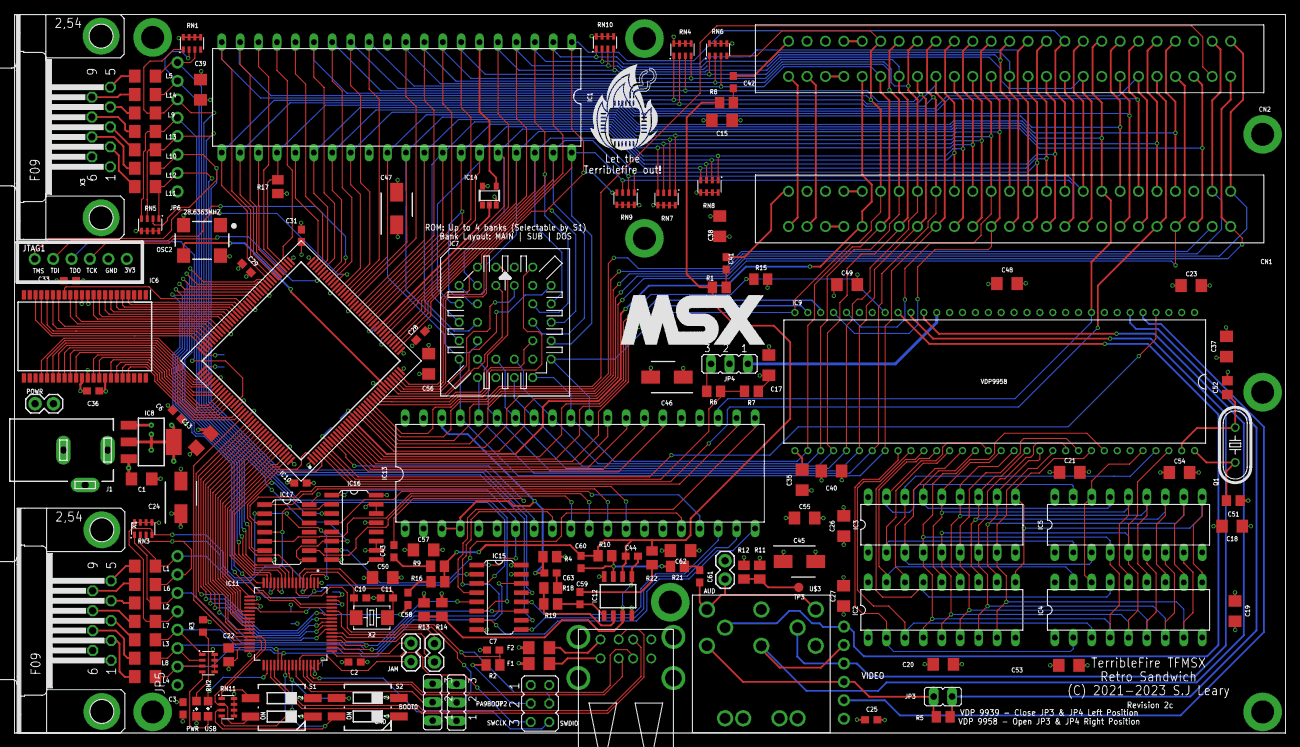
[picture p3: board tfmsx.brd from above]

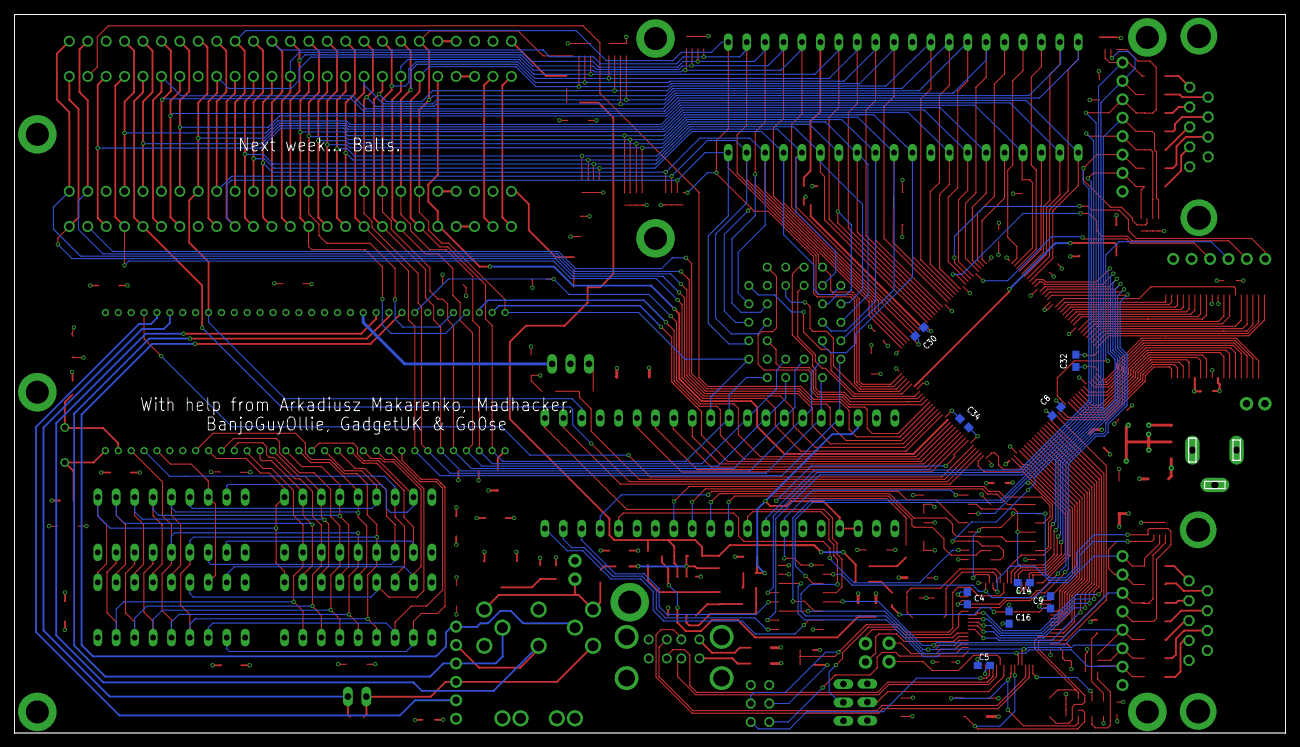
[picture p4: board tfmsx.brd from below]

Board: 4 copper layers, 175.3 x 99.1 mm, 156 parts (9 on the bottom side), 238 nets.

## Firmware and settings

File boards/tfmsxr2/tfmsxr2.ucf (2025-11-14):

# Copyright (C) 2016-2017, Stephen J. Leary
# All rights reserved.
#
# This file is part of TF530 (Terrible Fire 030 Accelerator)
#
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
NET "CLK28M"      LOC="30";
NET "EXCS1"      LOC="21";
NET "EXCS2"      LOC="20";
NET "EXCS12"      LOC="22";
NET "EXSLTSL1"      LOC="23";
NET "EXSLTSL2"      LOC="24";
NET "INT"      LOC="70";
NET "M1"      LOC="66";
NET "RESET"      LOC="69";
NET "RFSH"      LOC="61";
NET "SCE"      LOC="97";
NET "SLOT_INT"      LOC="19";
NET "VDPR"      LOC="14";
NET "VDPW"      LOC="15";
NET "VDP_INT"      LOC="16";
NET "VRESET"      LOC="7";
NET "A<0>"      LOC="58";
NET "A<1>"      LOC="57";
NET "A<2>"      LOC="54";
NET "A<3>"      LOC="52";
NET "A<4>"      LOC="50";
NET "A<5>"      LOC="48";
NET "A<6>"      LOC="45";
NET "A<7>"      LOC="43";
NET "A<8>"      LOC="40";
NET "A<9>"      LOC="38";
NET "A<10>"      LOC="34";
NET "A<11>"      LOC="33";
NET "A<12>"      LOC="35";
NET "A<13>"      LOC="39";
NET "A<14>"      LOC="41";
NET "A<15>"      LOC="44";
NET "PORTB<0>"      LOC="136";
NET "PORTB<1>"      LOC="135";
NET "PORTB<2>"      LOC="134";
NET "PORTB<3>"      LOC="133";
NET "PORTB<4>"      LOC="132";
NET "PORTB<5>"      LOC="131";
NET "PORTB<6>"      LOC="130";
NET "PORTB<7>"      LOC="129";
NET "ARMINT"      LOC="82";
NET "BDIR"      LOC="5";
NET "BUSAK"      LOC="77";
NET "BUSRQ"      LOC="71";

NET "CLKCPU"      LOC="46";
NET "D<0>"      LOC="64";
NET "D<1>"      LOC="68";
NET "D<2>"      LOC="59";
NET "D<3>"      LOC="51";
NET "D<4>"      LOC="49";
NET "D<5>"      LOC="53";
NET "D<6>"      LOC="56";
NET "D<7>"      LOC="60";
NET "HALT"      LOC="76";
NET "INTSIG<4>"      LOC="140";
NET "INTSIG<5>"      LOC="139";
NET "INTSIG<6>"      LOC="138";
NET "INTSIG<7>"      LOC="137";
NET "INTSIG<18>"      LOC="88";
NET "INTSIG<19>"      LOC="87";
NET "INTSIG<20>"      LOC="86";
NET "INTSIG<21>"      LOC="85";
NET "INTSIG<22>"      LOC="83";
NET "IORQ"      LOC="80";
NET "MREQ"      LOC="78";
NET "PORTC<0>"      LOC="3";
NET "PORTC<1>"      LOC="2";
NET "PORTC<2>"      LOC="143";
NET "PORTC<3>"      LOC="142";
NET "NMI"      LOC="74";
NET "PPI_SND"      LOC="9";
NET "PSGCLK"      LOC="4";
NET "RAMSLOT<0>"      LOC="115";
NET "RAMSLOT<1>"      LOC="120";
NET "RAMSLOT<2>"      LOC="121";
NET "RAMSLOT<3>"      LOC="124";
NET "RAMSLOT<4>"      LOC="125";
NET "RD"      LOC="81";
NET "ROMA<14>"      LOC="31";
NET "ROMA<15>"      LOC="28";
NET "ROMA<16>"      LOC="27";
NET "ROMA<17>"      LOC="25";
NET "ROMA<18>"      LOC="32";
NET "ROMOE"      LOC="26";
NET "ROMSEL<0>"      LOC="128";
NET "ROMSEL<1>"      LOC="126";
NET "SA<0>"      LOC="92";
NET "SA<1>"      LOC="93";
NET "SA<2>"      LOC="94";
NET "SA<3>"      LOC="95";
NET "SA<4>"      LOC="96";
NET "SA<5>"      LOC="103";
NET "SA<6>"      LOC="104";
NET "SA<7>"      LOC="105";
NET "SA<8>"      LOC="106";
NET "SA<9>"      LOC="107";
NET "SA<10>"      LOC="110";
NET "SA<11>"      LOC="111";
NET "SA<12>"      LOC="112";
NET "SA<13>"      LOC="113";
NET "SD<0>"      LOC="98";
NET "SD<1>"      LOC="100";
NET "SD<2>"      LOC="101";
NET "SD<3>"      LOC="102";
NET "SD<4>"      LOC="116";
NET "SD<5>"      LOC="117";
NET "SD<6>"      LOC="118";
NET "SD<7>"      LOC="119";
NET "SLOTCLK"      LOC="17";
NET "SWR"      LOC="91";
NET "VDP_SEL"      LOC="6";
NET "WAIT"      LOC="75";
NET "WR"      LOC="79";
NET "YMBC<1>"      LOC="13";
NET "YMBC<2>"      LOC="12";
NET "YMBDIR"      LOC="11";
NET "YMSEL"      LOC="10";

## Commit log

2025-11-14 Initial commit of the public version of the tfmsx. Cleaned the repo updated the builds @
    [tfmsx.brd, tfmsx.sch]
2025-11-14 Add VDP configuration documentation and Eagle Makefile instructions
    - Document VDP jumper settings (JP3/JP4) for V9938 and V9958 chips
    - Add Eagle Makefile documentation for Gerber generation
    - Clarify JP3 is single-position and JP4 is two-position jumper
    - Update testing section with Docker support details
    - Add MSX ROM documentation
    - Update license to CC-BY-ND 4.0
    - Fix repository structure to reflect actual directories
2025-11-14 adding bom extract
2025-11-15 Add GitHub Actions build status badges to README
    - Add badges for Gerber generation, schematic PDF, and BOM workflows
    - Badges link directly to workflow runs showing pass/fail status
2025-11-15 Add comprehensive test suite for bus operations
    - Add CLK28M clock definition to clocks.vinc
    - Enhance bus_fixture.vinc with missing wire declarations
    - Add test_sram_access.v: Tests SRAM read/write and mapper control
    - Add test_rom_access.v: Tests ROM access and output enable signals
    - Add test_vdp_io.v: Tests VDP I/O ports (0x98-0x9B)
    - Add test_slot_access.v: Tests MSX slot system and memory mapping
    All tests verify:
    - Proper signal timing and activation
    - Correct address decoding
    - Memory mapping and bank selection
    - I/O port access patterns
    Test results: 5/5 tests passing
2025-11-15 Update README to reflect current project structure
    - Add comprehensive testing as a key feature
    - Update repository structure diagram with detailed test file listing
    - Include CI/CD workflows in structure diagram
    - Remove references to JAMMA adapter (not in current scope)
    - Clarify Eagle files: current design vs historical revisions
    - Better organize testsuite structure showing all test files
    The README now accurately reflects the complete project including
    the new comprehensive test suite and CI/CD integration.
2025-11-15 Add component placement (CPL) extraction script
    - Create extract_cpl.py to generate JLCPCB-compatible CPL files from .brd
    - Parse Eagle board XML to extract component positions, layers, rotations
    - Handle mirrored components (bottom layer) correctly
    - Add Makefile targets: cpl, jlcpcb (generates both BOM and CPL)
    - Update Makefile help text and clean targets
    - Minor update to extract_bom.py for consistency
    Usage:
    make cpl - Generate component placement list
    make jlcpcb - Generate both BOM and CPL for assembly
    Output matches JLCPCB format with proper CSV structure:
    Designator,Mid X,Mid Y,Layer,Rotation
    [tfmsx_cpl.csv]
2025-11-15 Rename jlcpcb target to assembly and update workflow
    - Rename Makefile target from 'jlcpcb' to 'assembly' (more generic)
    - Rename GitHub workflow from generate_bom.yml to generate_assembly.yml
    - Update workflow to generate both BOM and CPL files
    - Update workflow to upload both files as separate artifacts
    - Update README badge to reflect new workflow name
    - Update README repository structure diagram
    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
2025-11-15 Add GitHub Actions workflow for CPLD firmware build
    Adds automated CPLD firmware building on push to rtl/ or boards/ directories.
    The workflow builds firmware for all boards and uploads JED files and release
    packages as artifacts.
    Also adds Build CPLD Firmware badge to README.
2025-11-15 Modify firmware build to include git version in JED filename
    Changes:
    - JED files now include short git hash in filename (e.g., tfmsxr2_top_a0c6df1.jed)
    - GitHub Actions workflow now only uploads JED files (removed ZIP packaging)
    - Added --platform linux/amd64 flag to Docker commands for ARM Mac compatibility
    - Updated flash target to use wildcard pattern for versioned JED files
    This makes it easy to identify which git revision a JED file was built from.
2025-11-15 Fix git version passing to Docker build and remove duplicate JED files
    - Pass GITVERSION from board Makefile (where git is accessible) to CPLD Makefile
    - Allow GITVERSION to be overridden as a parameter in Makefile.cpld
    - Remove duplicate non-versioned JED file after creating versioned one
    - This ensures git version is correctly embedded in JED filename even in Docker builds
    Fixes issue where GITVERSION was "unknown" in GitHub Actions builds.
    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
2025-11-15 Pass GITVERSION as environment variable to Docker in GitHub Actions
    In GitHub Actions, git commands inside the Docker container may not work
    reliably. This change evaluates GITVERSION outside Docker in the GitHub
    Actions runner where git is available, then passes it into the Docker
    container as an environment variable.
    - Evaluate GITVERSION before docker run in GitHub Actions workflow
    - Pass GITVERSION to Docker container via -e flag
    - Use ?= in board Makefile to prefer environment variable over shell command
    This ensures JED files get proper git hash even in CI builds.
    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
2025-11-15 Add release workflow to package all build artifacts
    Creates a comprehensive release package containing:
    - CPLD firmware (JED files)
    - PCB Gerbers for manufacturing
    - BOM and CPL for assembly services
    - Schematic PDF documentation
    The workflow can be triggered by:
    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
2025-11-15 Fix Gerber generation in release workflow
    Create output directory before running Eagle CAM job to avoid
    'Output dir doesn't exist' error.
2025-11-15 updating permissions for workflow builds
    [tfmsx_cpl.csv]

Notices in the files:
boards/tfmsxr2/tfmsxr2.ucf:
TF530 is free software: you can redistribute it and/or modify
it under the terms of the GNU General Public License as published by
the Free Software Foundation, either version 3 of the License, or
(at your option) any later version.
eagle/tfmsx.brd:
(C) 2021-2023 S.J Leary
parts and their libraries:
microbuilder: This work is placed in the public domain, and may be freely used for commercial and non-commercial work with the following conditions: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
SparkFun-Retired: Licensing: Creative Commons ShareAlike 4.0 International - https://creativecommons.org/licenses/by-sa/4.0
